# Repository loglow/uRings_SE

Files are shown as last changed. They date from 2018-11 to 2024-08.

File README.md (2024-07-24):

# µRings SE (uRings, microRings) Eurorack [Rev D]

## 8HP Eurorack module | Resonator

[μRings SE](http://urings-se.com) is a resonator, transforming unpitched external excitation signals into pitched sounds by modeling the vibrations of bars, tubes, and strings.

This re-engineered Eurorack module updates and simplifies the classic [Mutable Instruments Rings](https://mutable-instruments.net/modules/rings/) design by miniaturizing the module from 14HP to 8HP and redesigning the front panel layout without eliminating any original functionality.

Fully compatible with upstream Rings firmware. Includes power cable, mounting hardware, and a one-year warranty. Designed and built with care by [Tall Dog Electronics](http://tall-dog.com) in Western Massachusetts. Licensed [CC BY-SA 4.0](https://creativecommons.org/licenses/by-sa/4.0/) open source hardware.

- **Height:** 3U (128.5 mm)
- **Width:** 8HP (40.3 mm)
- **Depth:** 43 mm (with power)
- **+12V:** 120 mA (average)
- **-12V:** 5 mA (average)

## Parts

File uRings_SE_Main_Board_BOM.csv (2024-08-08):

Ref | Qty | Desc | Mfg | MPN
C1 C2 C5 C12 C13 C15 C16 C18 C19 C21 C22 C26 C33 C34 C35 C36 C44 C47 | 18 | CAP CER 0.1UF 16V X7R 0603 | Samsung Electro-Mechanics | CL10B104KO8NNWC
C3 C9 | 2 | CAP CER 2.2UF 10V X7R 0603 | TDK Corporation | C1608X7R1A225M080AC
C4 C7 C20 C25 C32 C40 | 6 | CAP CER 18PF 50V C0G/NPO 0603 | YAGEO | CC0603FPNPO9BN180
C6 C11 C17 C23 | 4 | CAP CER 1UF 25V X7R 0603 | Taiyo Yuden | TMK107B7105KA-T
C8 C10 C14 C24 C27 C28 C41 C42 | 8 | CAP ALUM 10UF 20% 25V SMD | Würth Elektronik | 865230440002
C29 C30 C31 C38 | 4 | CAP CER 10000PF 50V C0G 0603 | TDK Corporation | C1608C0G1H103J080AA
C37 C39 | 2 | CAP CER 2200PF 50V C0G 0603 | TDK Corporation | C1608C0G1H222J080AA
C43 | 1 | CAP CER 220PF 50V C0G/NPO 0603 | YAGEO | CC0603FPNPO9BN221
C45 C46 C49 | 3 | CAP ALUM 47UF 20% 25V SMD | Würth Elektronik | 865230445005
C48 | 1 | CAP ALUM 22UF 20% 25V SMD | Würth Elektronik | 865230443003
D1 | 1 | DIODE ARR SCHOTT 30V 200MA SOT23 | Toshiba Semiconductor and Storage | TBAT54S,LM
D2 D3 | 2 | DIODE SCHOTTKY 40V 1A SOD123 | Diodes Incorporated | 1N5819HW-7-F
H1 H2 H3 H4 | 4 | CONN HDR 10POS 0.1 GOLD PCB | Sullins Connector Solutions | PPPC052LFBN-RC
H5 | 1 | CONN HEADER VERT 10POS 1.27MM | CNC Tech | 3220-10-0100-00
H6 | 1 | DO NOT POPULATE | DNP | DNP
H7 | 1 | CONN HEADER VERT 10POS 2.54MM | On Shore Technology Inc. | 302-S101
L1 L2 L3 | 3 | FERRITE BEAD 1K OHM 0603 1LN | Würth Elektronik | 742792664
Q1 | 1 | TRANS NPN 40V 0.2A SOT23-3 | Diodes Incorporated | MMBT3904-7-F
R1 R11 | 2 | RES SMD 10K OHM 1% 1/10W 0603 | Panasonic Electronic Components | ERJ-3EKF1002V
R2 R3 | 2 | RES SMD 100 OHM 1% 1/10W 0603 | Panasonic Electronic Components | ERJ-3EKF1000V
R4 | 1 | RES 3.3M OHM 0.1% 1/4W 1206 | Susumu | RG3216P-3304-B-T1
R5 R6 R48 | 3 | RES SMD 2.2K OHM 1% 1/10W 0603 | Panasonic Electronic Components | ERJ-3EKF2201V
R7 R45 | 2 | RES SMD 36K OHM 0.1% 1/10W 0603 | Susumu | RG1608P-363-B-T5
R8 R9 R10 R18 R26 R38 R39 R40 | 8 | RES SMD 100K OHM 0.1% 1/10W 0603 | Susumu | RG1608P-104-B-T5
R12 R13 R14 R35 R36 | 5 | RES SMD 120K OHM 0.1% 1/10W 0603 | Susumu | RG1608P-124-B-T5
R15 R16 R17 R32 R33 | 5 | RES SMD 20K OHM 0.1% 1/10W 0603 | Susumu | RG1608P-203-B-T5
R19 R21 R23 R25 R29 R31 R34 | 7 | RES SMD 47K OHM 0.1% 1/10W 0603 | Susumu | RG1608P-473-B-T5
R20 R30 R46 | 3 | RES SMD 6.8K OHM 0.1% 1/10W 0603 | Susumu | RG1608P-682-B-T5
R22 R24 | 2 | RES SMD 1K OHM 0.1% 1/10W 0603 | Susumu | RG1608P-102-B-T5
R27 | 1 | RES SMD 1M OHM 0.1% 1/4W 1206 | Susumu | RG3216P-1004-B-T1
R28 | 1 | RES SMD 470K OHM 0.1% 1/4W 1206 | Susumu | RG3216P-4703-B-T1
R37 | 1 | RES SMD 180K OHM 0.1% 1/10W 0603 | Susumu | RG1608P-184-B-T5
R41 R42 R43 R44 | 4 | RES SMD 180 OHM 1% 1/10W 0603 | Panasonic Electronic Components | ERJ-3EKF1800V
R47 | 1 | RES SMD 4.7 OHM 5% 1/4W 1206 | Panasonic Electronic Components | ERJ-8GEYJ4R7V
U1 | 1 | IC MCU 32BIT 1MB FLASH 64LQFP | STMicroelectronics | STM32F405RGT6
U2 | 1 | IC MUX 8:1 120OHM 16TSSOP | Nexperia USA Inc. | 74HC4051PW,118
U3 | 1 | IC CODEC AUDIO LOW POWER 28LFCSP | Analog Devices Inc. | SSM2603CPZ-REEL7
U4 | 1 | IC OPAMP GP 4 CIRCUIT 14TSSOP | Microchip Technology | MCP6004T-E/ST
U5 | 1 | IC OPAMP GP 2 CIRCUIT 8MSOP | Microchip Technology | MCP6002T-I/MS
U6 | 1 | IC OPAMP JFET 2 CIRCUIT 8TSSOP | Texas Instruments | TL072CPWR
U7 | 1 | IC REG LINEAR 3.3V 800MA SOT223 | Texas Instruments | LM1117IMP-3.3/NOPB
U8 | 1 | IC VREF SHUNT 0.5% SOT23-3 | Texas Instruments | LM4040C10IDBZR
X1 | 1 | CRYSTAL 8.0000MHZ 18PF SMD | Abracon LLC | ABM3-8.000MHZ-D2Y-T
X2 | 1 | CRYSTAL 12.2880MHZ 18PF SMD | Abracon LLC | ABM3-12.288MHZ-D2Y-T

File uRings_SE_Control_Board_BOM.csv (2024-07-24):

Ref | Qty | Desc | Mfg | MPN
D1 D2 | 2 | LED GRN/RED DIFF 3MM ROUND T/H | Kingbright | WP3VEGW
H1 H2 H3 H4 | 4 | CONN HEADER 10POS .100 STR 15AU | Amphenol ICC (FCI) | 67997-210HLF
J1 J2 J3 J4 J5 J6 J7 J8 J9 J10 | 10 | 3.5MM JACK VERTICAL PCB MOUNT | Wenzhou QingPu | WQP-WQP518MA
P1 P3 P5 P7 P9 | 5 | POT 9MM LINEAR B10K WHITE LINE | Song Huei | R0904N-B10K,L-25KQ/LWS
P2 P4 P6 P8 P10 | 5 | POT 9MM LINEAR B10K WHITE LINE CENTER DETENT | Song Huei | R0904N-B10K,L-25KQ/LWS/CC
S1 S2 | 2 | SWITCH TACTILE SPST-NO 0.05A 12V | E-Switch | TL1105DF160Q

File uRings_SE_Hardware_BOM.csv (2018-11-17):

Description | Quantity
Thonkiconn Knurled Nut, Steel, M6 | 10
Threaded Hex Standoff, Brass, M2.5 x 11 mm | 2
Standoff Screw, Button Head, Hex Socket, M2.5 x 6 mm | 4

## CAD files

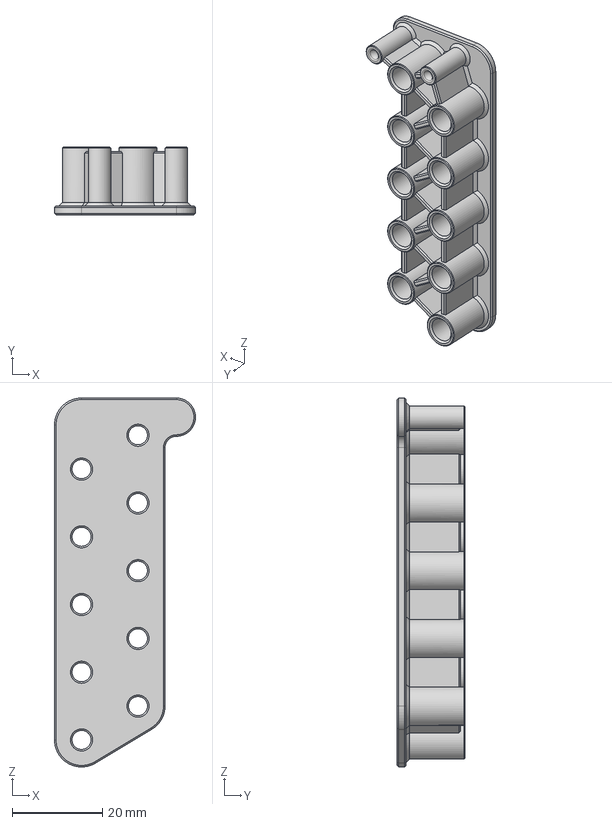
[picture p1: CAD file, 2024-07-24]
uRings_SE_Assembly_Cap.step
31.2 x 15.0 x 81.7 mm

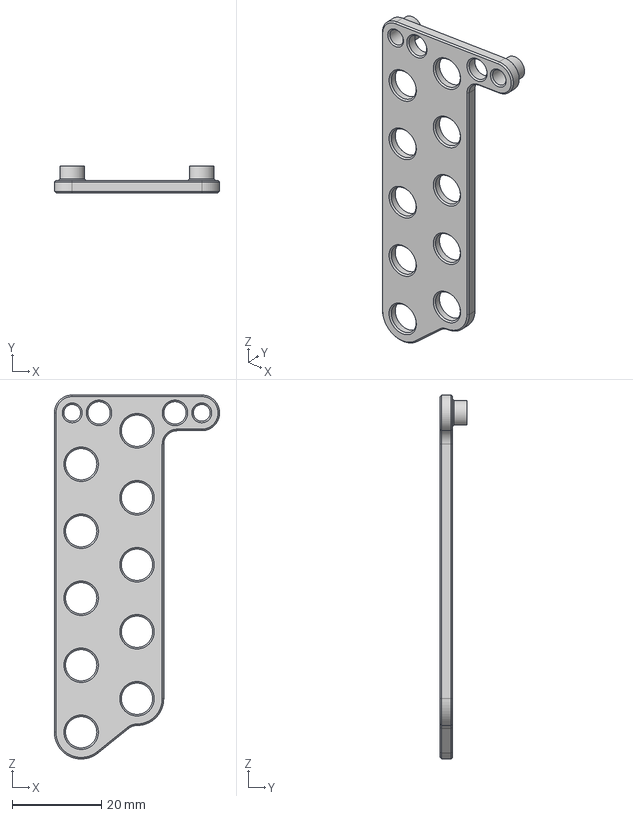
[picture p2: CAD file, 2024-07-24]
uRings_SE_Assembly_Spacer.step
37.0 x 6.00 x 81.5 mm

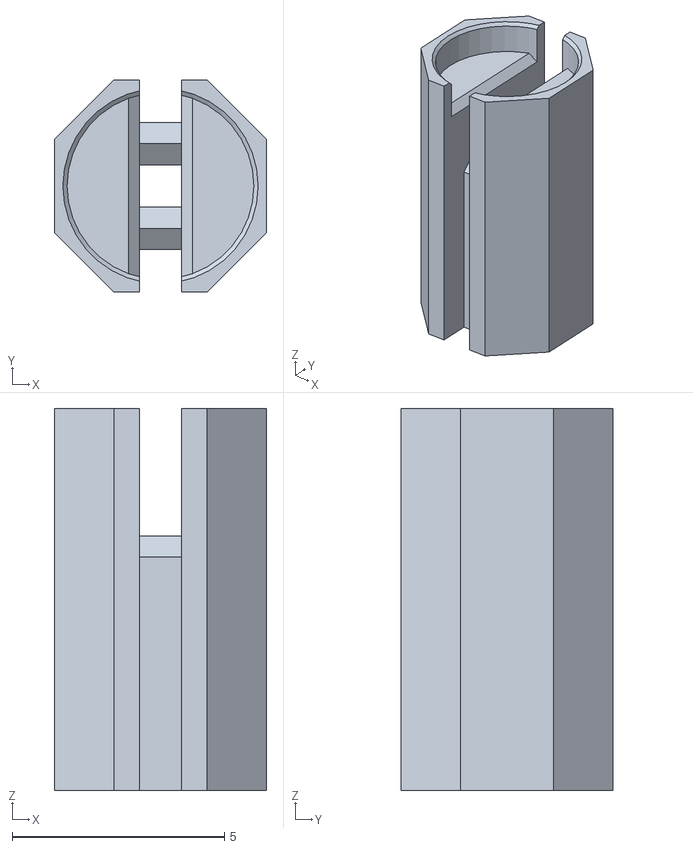
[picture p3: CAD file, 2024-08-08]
uRings_SE_LED_Spacer.stl
5.00 x 5.00 x 9.00

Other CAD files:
uRings_SE_Assembly_Cap.stl
uRings_SE_Assembly_Spacer.stl
uRings_SE_Model.skp

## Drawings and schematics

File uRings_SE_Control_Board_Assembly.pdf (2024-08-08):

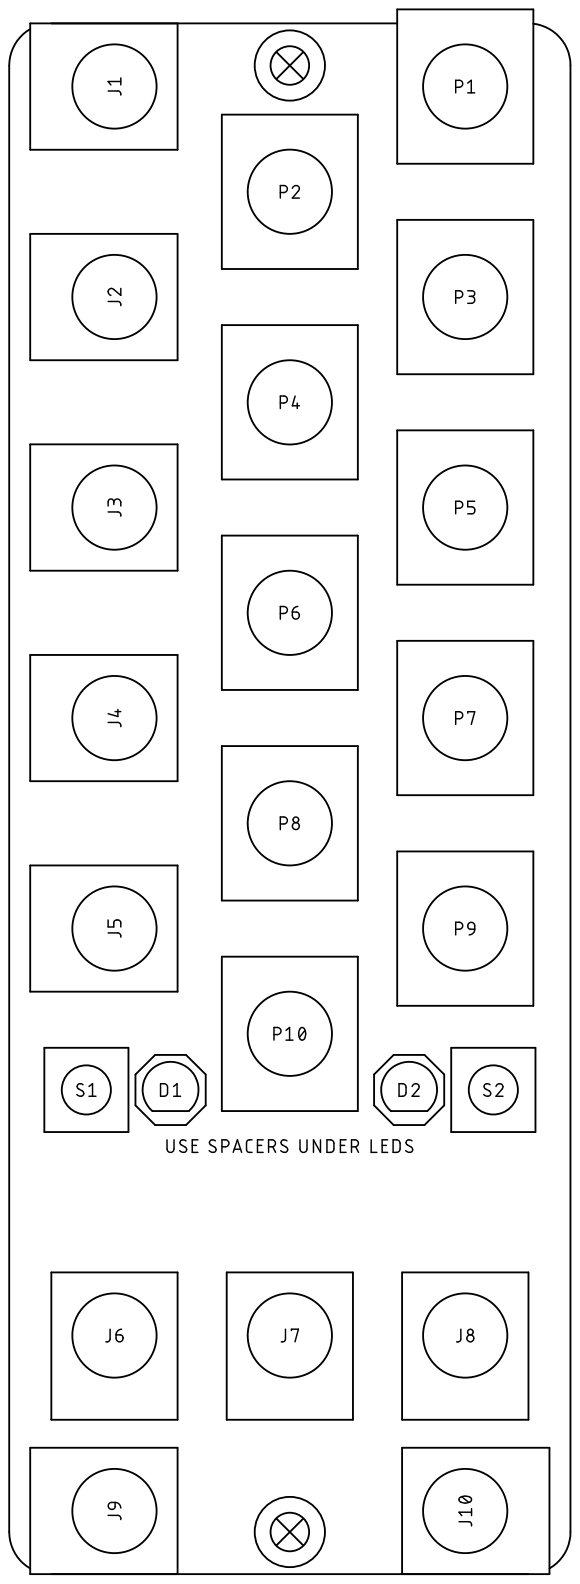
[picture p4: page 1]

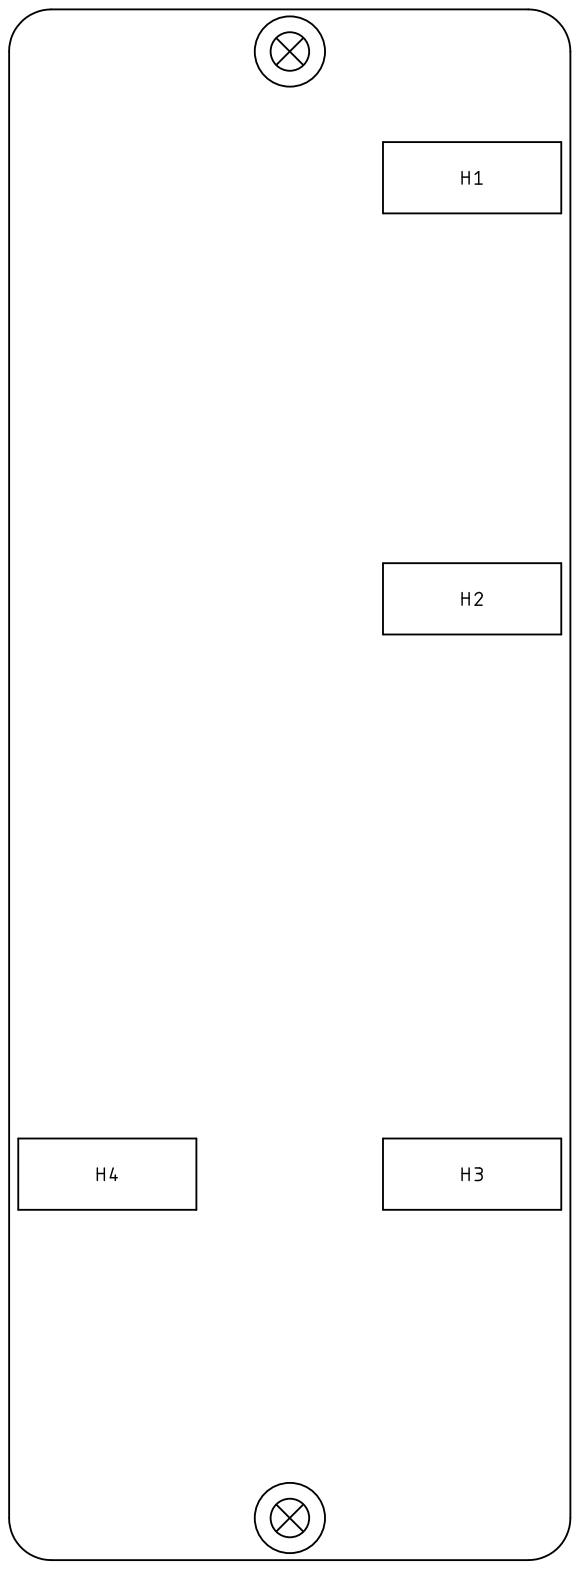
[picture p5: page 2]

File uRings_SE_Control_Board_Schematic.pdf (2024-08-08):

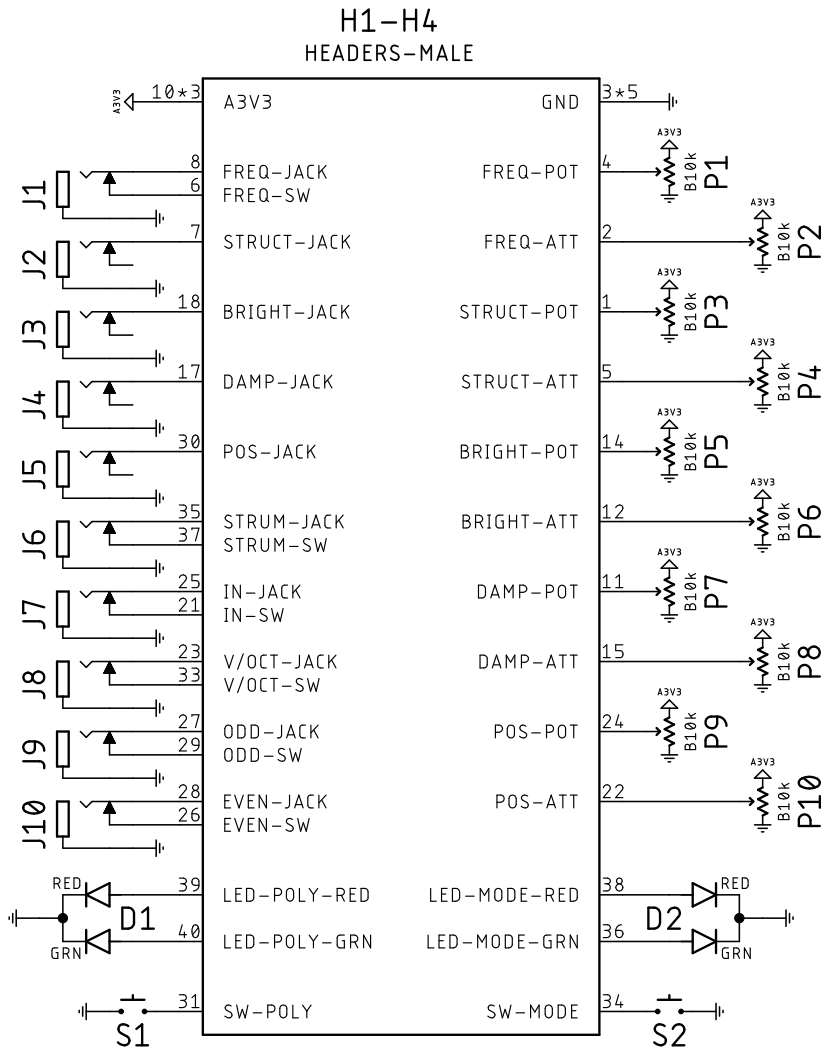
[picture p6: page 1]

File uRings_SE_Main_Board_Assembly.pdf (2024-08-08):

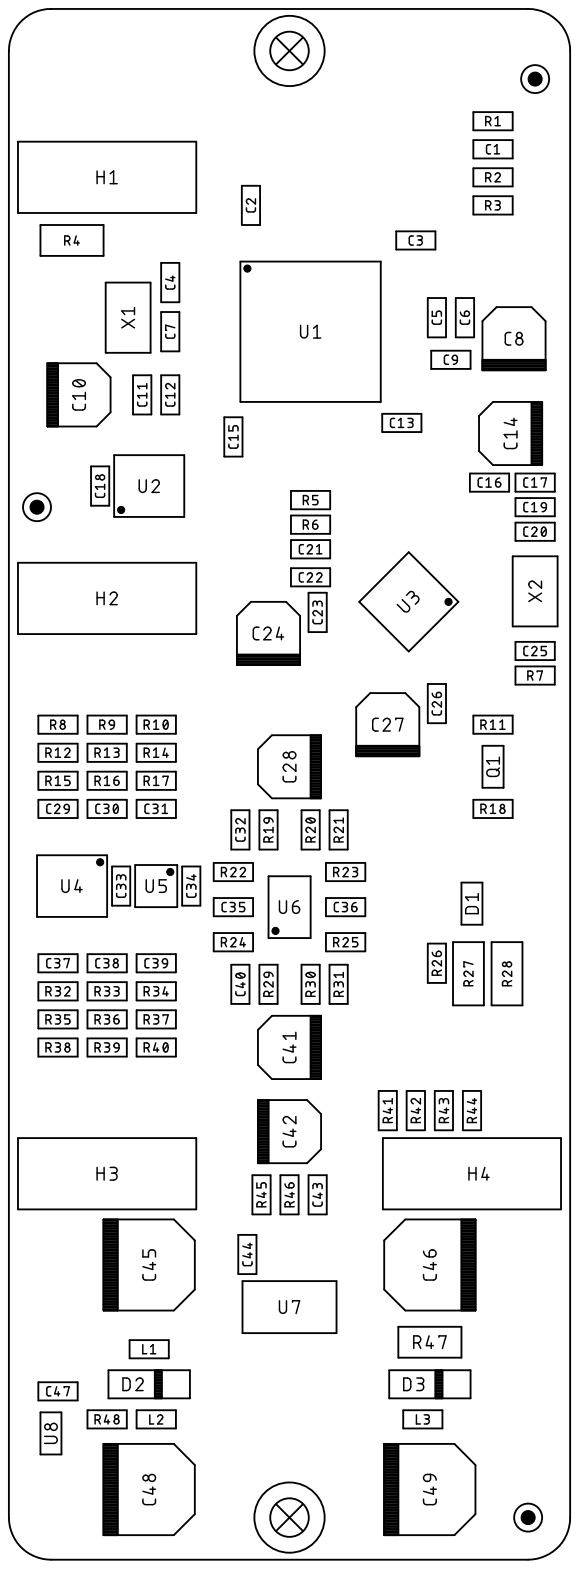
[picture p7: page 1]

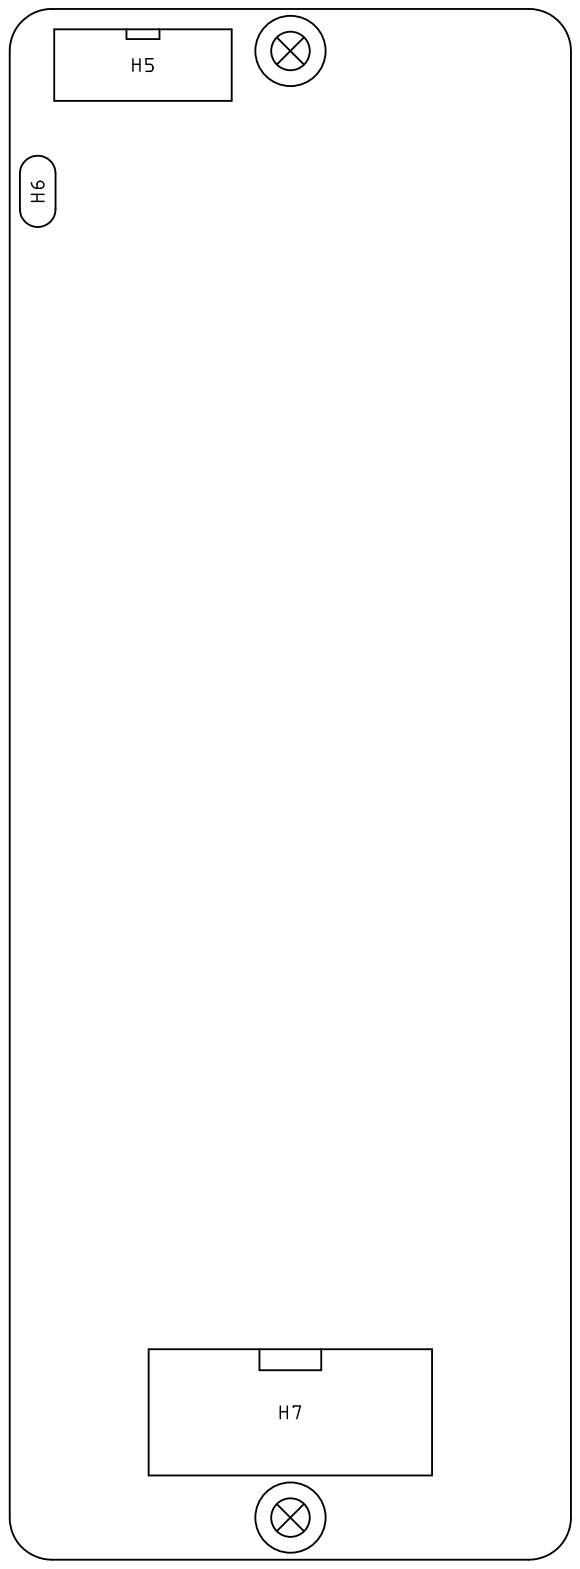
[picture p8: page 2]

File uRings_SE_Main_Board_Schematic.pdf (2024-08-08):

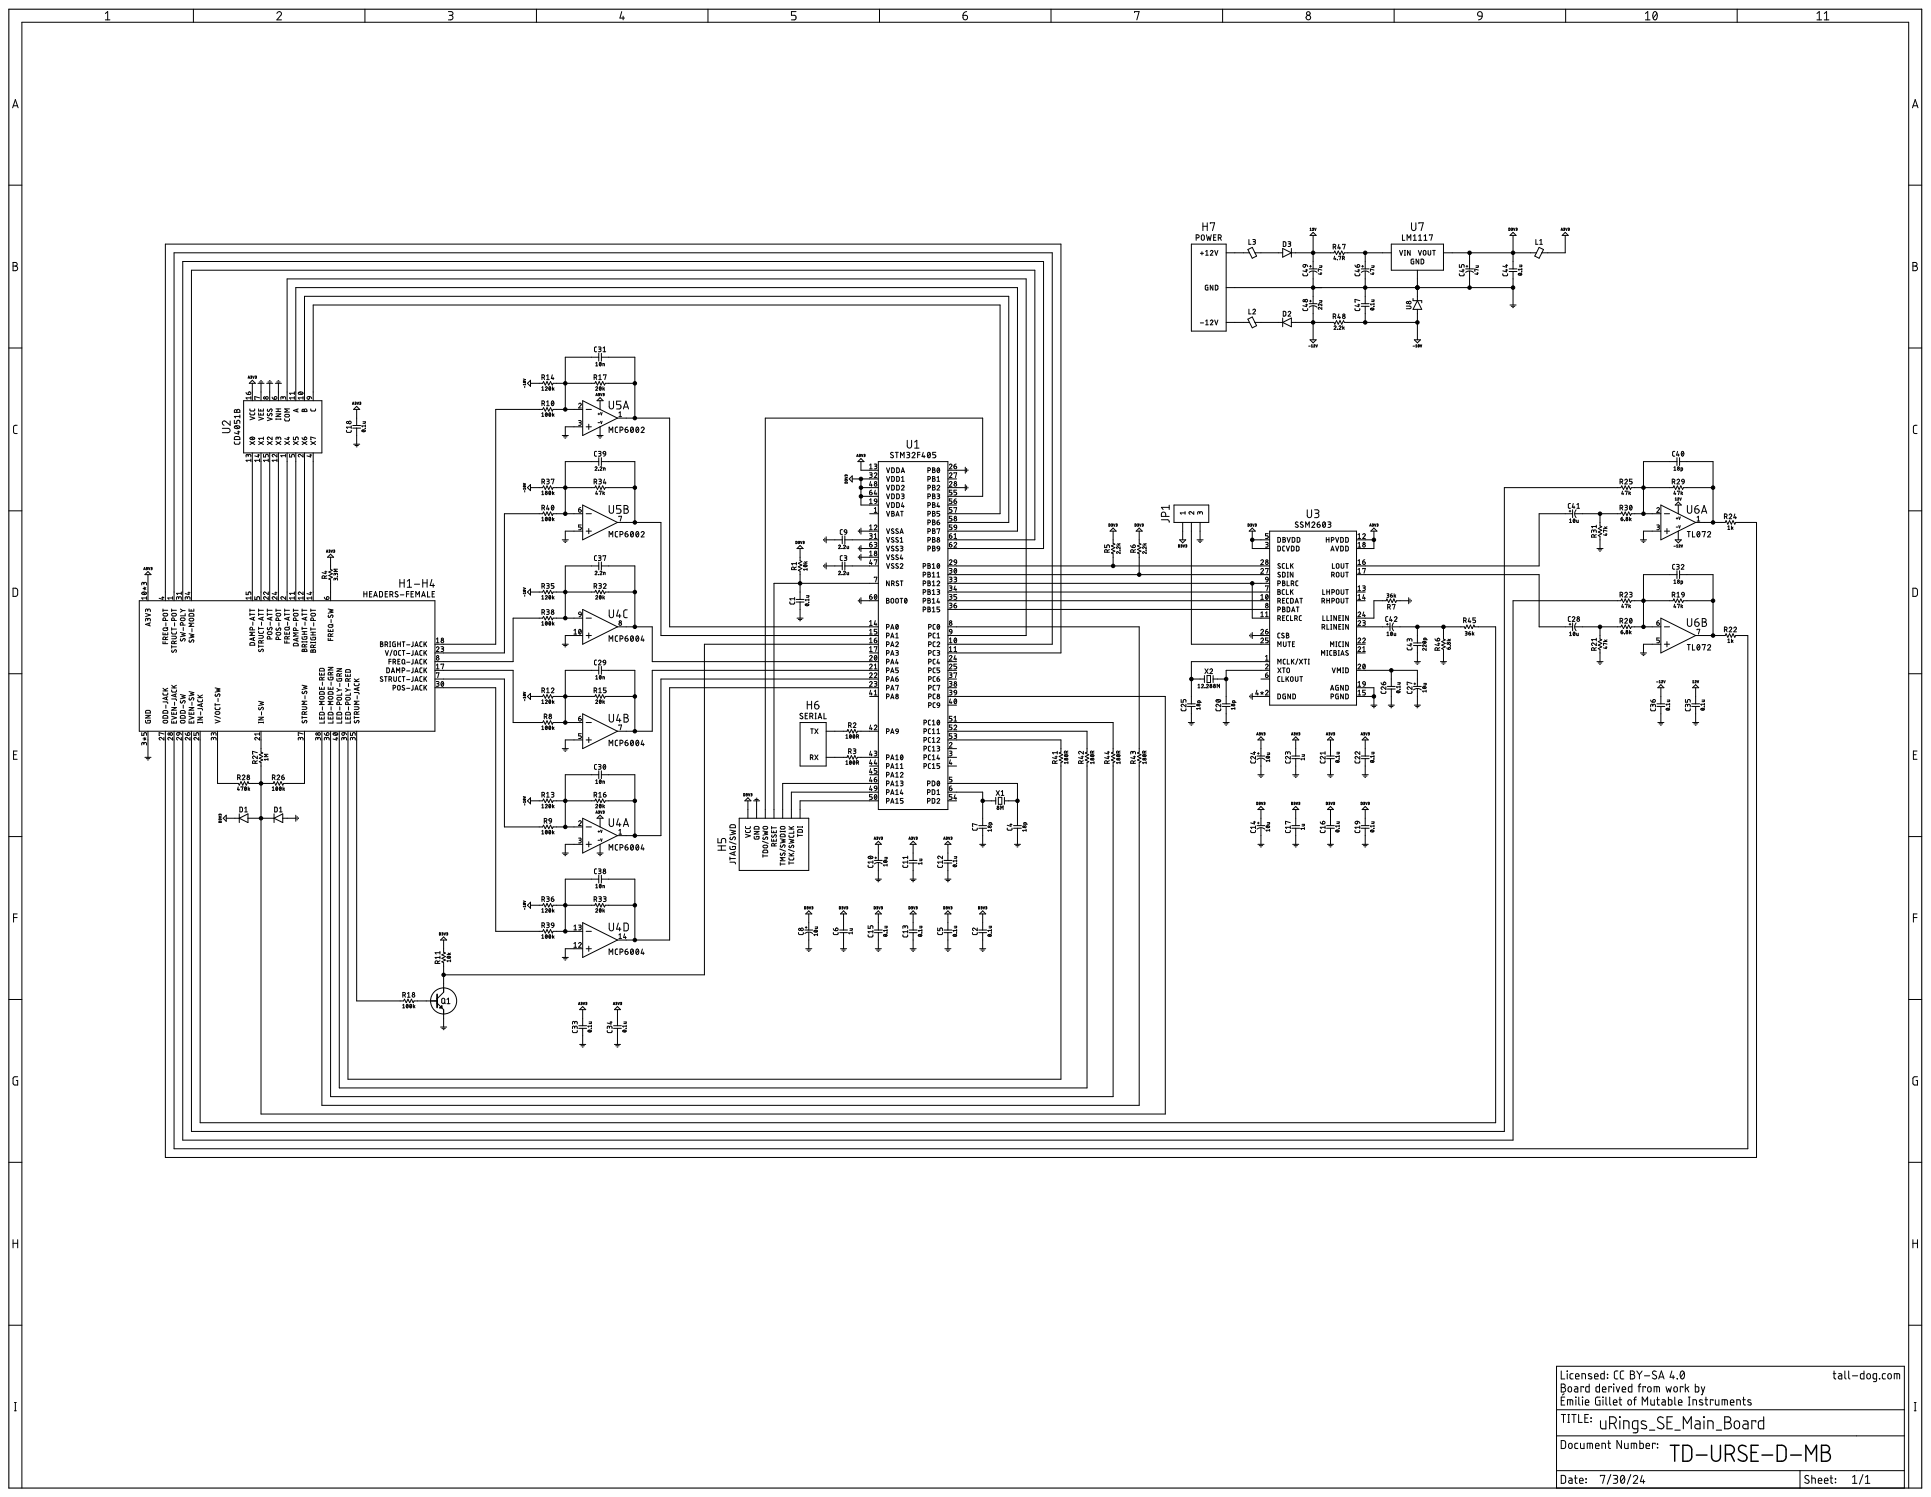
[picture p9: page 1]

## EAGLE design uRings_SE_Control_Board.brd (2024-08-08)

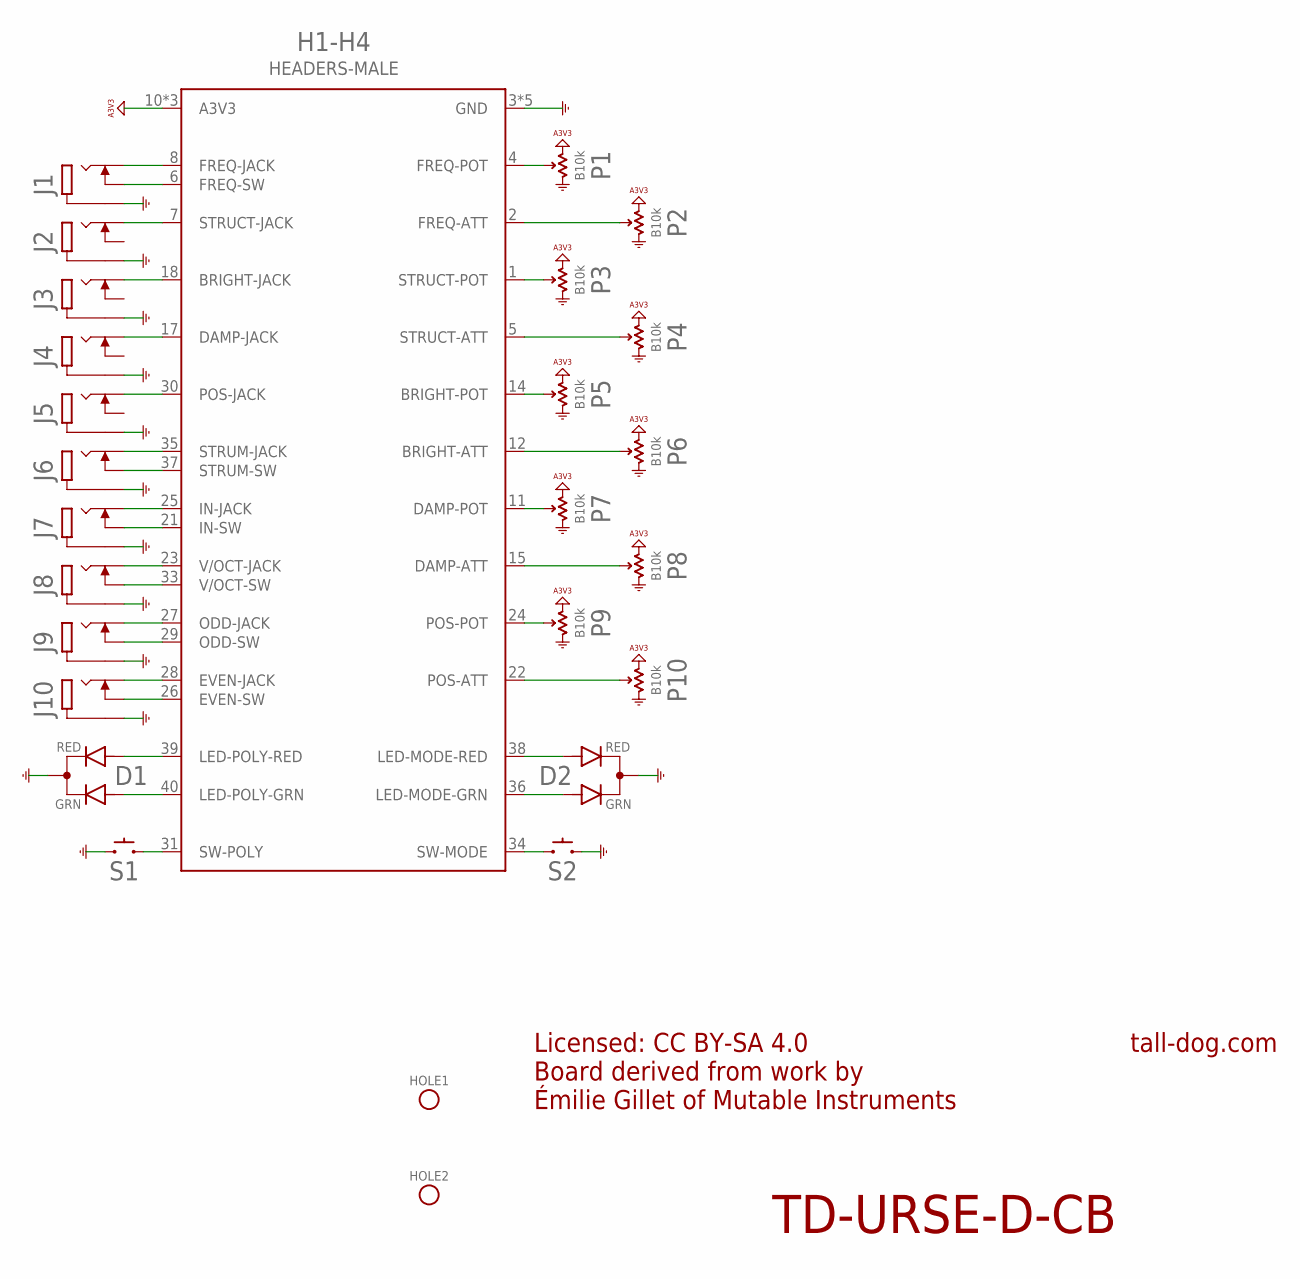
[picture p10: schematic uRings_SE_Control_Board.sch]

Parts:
D1, D2: LED-DUAL; LED-T1-3
H1-H4: HEADERS-MALE
HOLE1, HOLE2: HOLE; M2.5-HOLE
J1, J2, J3, J4, J5, J6, J7, J8, J9, J10: JACK
P1, P2, P3, P4, P5, P6, P7, P8, P9, P10: B10k; POT
S1, S2: SPST; TL1105

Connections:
A3V3: H1-H4.10 (A3V3), H1-H4.16 (A3V3), H1-H4.20 (A3V3), P1.P$1 (E), P2.P$1 (E), P3.P$1 (E), P4.P$1 (E), P5.P$1 (E), P6.P$1 (E), P7.P$1 (E), P8.P$1 (E), P9.P$1 (E), P10.P$1 (E)
BRIGHT-ATT: H1-H4.12 (BRIGHT-ATT), P6.P$2 (S)
BRIGHT-JACK: H1-H4.18 (BRIGHT-JACK), J3.P3 (3)
BRIGHT-POT: H1-H4.14 (BRIGHT-POT), P5.P$2 (S)
DAMP-ATT: H1-H4.15 (DAMP-ATT), P8.P$2 (S)
DAMP-JACK: H1-H4.17 (DAMP-JACK), J4.P3 (3)
DAMP-POT: H1-H4.11 (DAMP-POT), P7.P$2 (S)
EVEN-JACK: H1-H4.28 (EVEN-JACK), J10.P3 (3)
EVEN-SW: H1-H4.26 (EVEN-SW), J10.P2 (2)
FREQ-ATT: H1-H4.2 (FREQ-ATT), P2.P$2 (S)
FREQ-JACK: H1-H4.8 (FREQ-JACK), J1.P3 (3)
FREQ-POT: H1-H4.4 (FREQ-POT), P1.P$2 (S)
FREQ-SW: H1-H4.6 (FREQ-SW), J1.P2 (2)
GND: D1.2 (C), D2.2 (C), H1-H4.3 (GND), H1-H4.9 (GND), H1-H4.13 (GND), H1-H4.19 (GND), H1-H4.32 (GND), J1.P1 (1), J2.P1 (1), J3.P1 (1), J4.P1 (1), J5.P1 (1), J6.P1 (1), J7.P1 (1), J8.P1 (1), J9.P1 (1), J10.P1 (1), P1.P$3 (A), P2.P$3 (A), P3.P$3 (A), P4.P$3 (A), P5.P$3 (A), P6.P$3 (A), P7.P$3 (A), P8.P$3 (A), P9.P$3 (A), P10.P$3 (A), S1.1, S1.2 (1), S2.1, S2.2 (1)
IN-JACK: H1-H4.25 (IN-JACK), J7.P3 (3)
IN-SW: H1-H4.21 (IN-SW), J7.P2 (2)
LED-MODE-GRN: D2.3 (GRN), H1-H4.36 (LED-MODE-GRN)
LED-MODE-RED: D2.1 (RED), H1-H4.38 (LED-MODE-RED)
LED-POLY-GRN: D1.3 (GRN), H1-H4.40 (LED-POLY-GRN)
LED-POLY-RED: D1.1 (RED), H1-H4.39 (LED-POLY-RED)
ODD-JACK: H1-H4.27 (ODD-JACK), J9.P3 (3)
ODD-SW: H1-H4.29 (ODD-SW), J9.P2 (2)
POS-ATT: H1-H4.22 (POS-ATT), P10.P$2 (S)
POS-JACK: H1-H4.30 (POS-JACK), J5.P3 (3)
POS-POT: H1-H4.24 (POS-POT), P9.P$2 (S)
STRUCT-ATT: H1-H4.5 (STRUCT-ATT), P4.P$2 (S)
STRUCT-JACK: H1-H4.7 (STRUCT-JACK), J2.P3 (3)
STRUCT-POT: H1-H4.1 (STRUCT-POT), P3.P$2 (S)
STRUM-JACK: H1-H4.35 (STRUM-JACK), J6.P3 (3)
STRUM-SW: H1-H4.37 (STRUM-SW), J6.P2 (2)
SW-MODE: H1-H4.34 (SW-MODE), S2.3 (2), S2.4 (2)
SW-POLY: H1-H4.31 (SW-POLY), S1.3 (2), S1.4 (2)
V/OCT-JACK: H1-H4.23 (V/OCT-JACK), J8.P3 (3)
V/OCT-SW: H1-H4.33 (V/OCT-SW), J8.P2 (2)

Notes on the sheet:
Licensed: CC BY-SA 4.0 Board derived from work by Émilie Gillet of Mutable Instruments
tall-dog.com
TD-URSE-D-CB

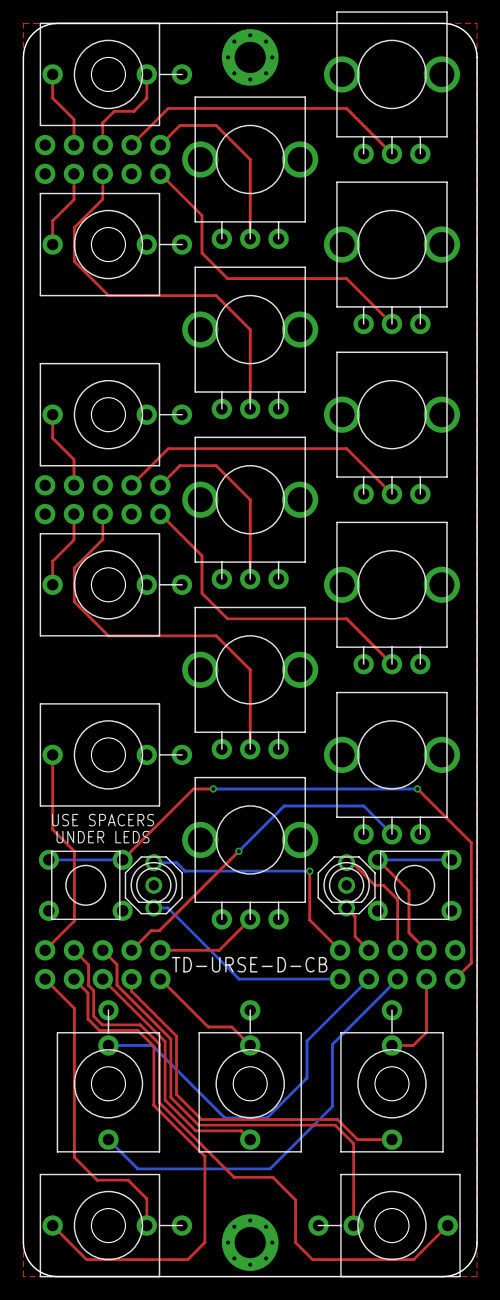
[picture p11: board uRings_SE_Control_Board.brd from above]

Board: 2 copper layers, 40.0 x 110.5 mm, 29 parts (0 on the bottom side), 34 nets.

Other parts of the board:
U$1, U$2: LED-SPACER

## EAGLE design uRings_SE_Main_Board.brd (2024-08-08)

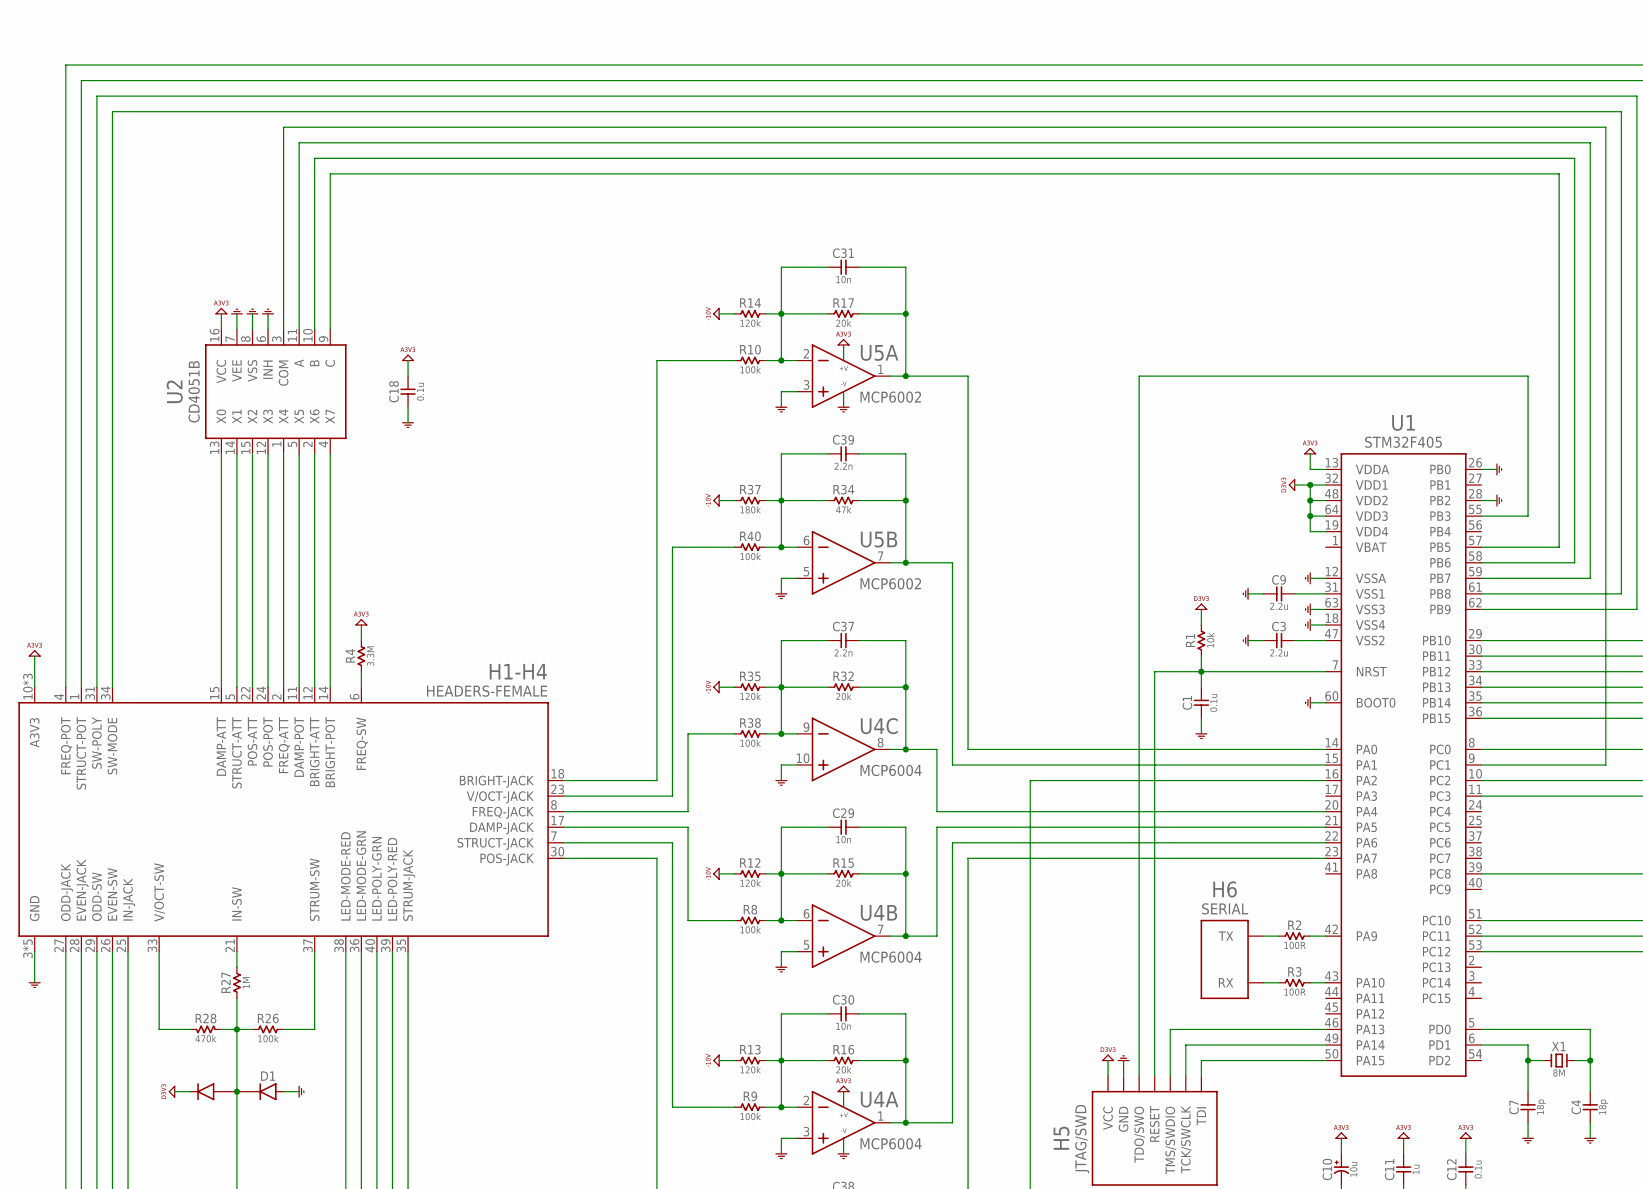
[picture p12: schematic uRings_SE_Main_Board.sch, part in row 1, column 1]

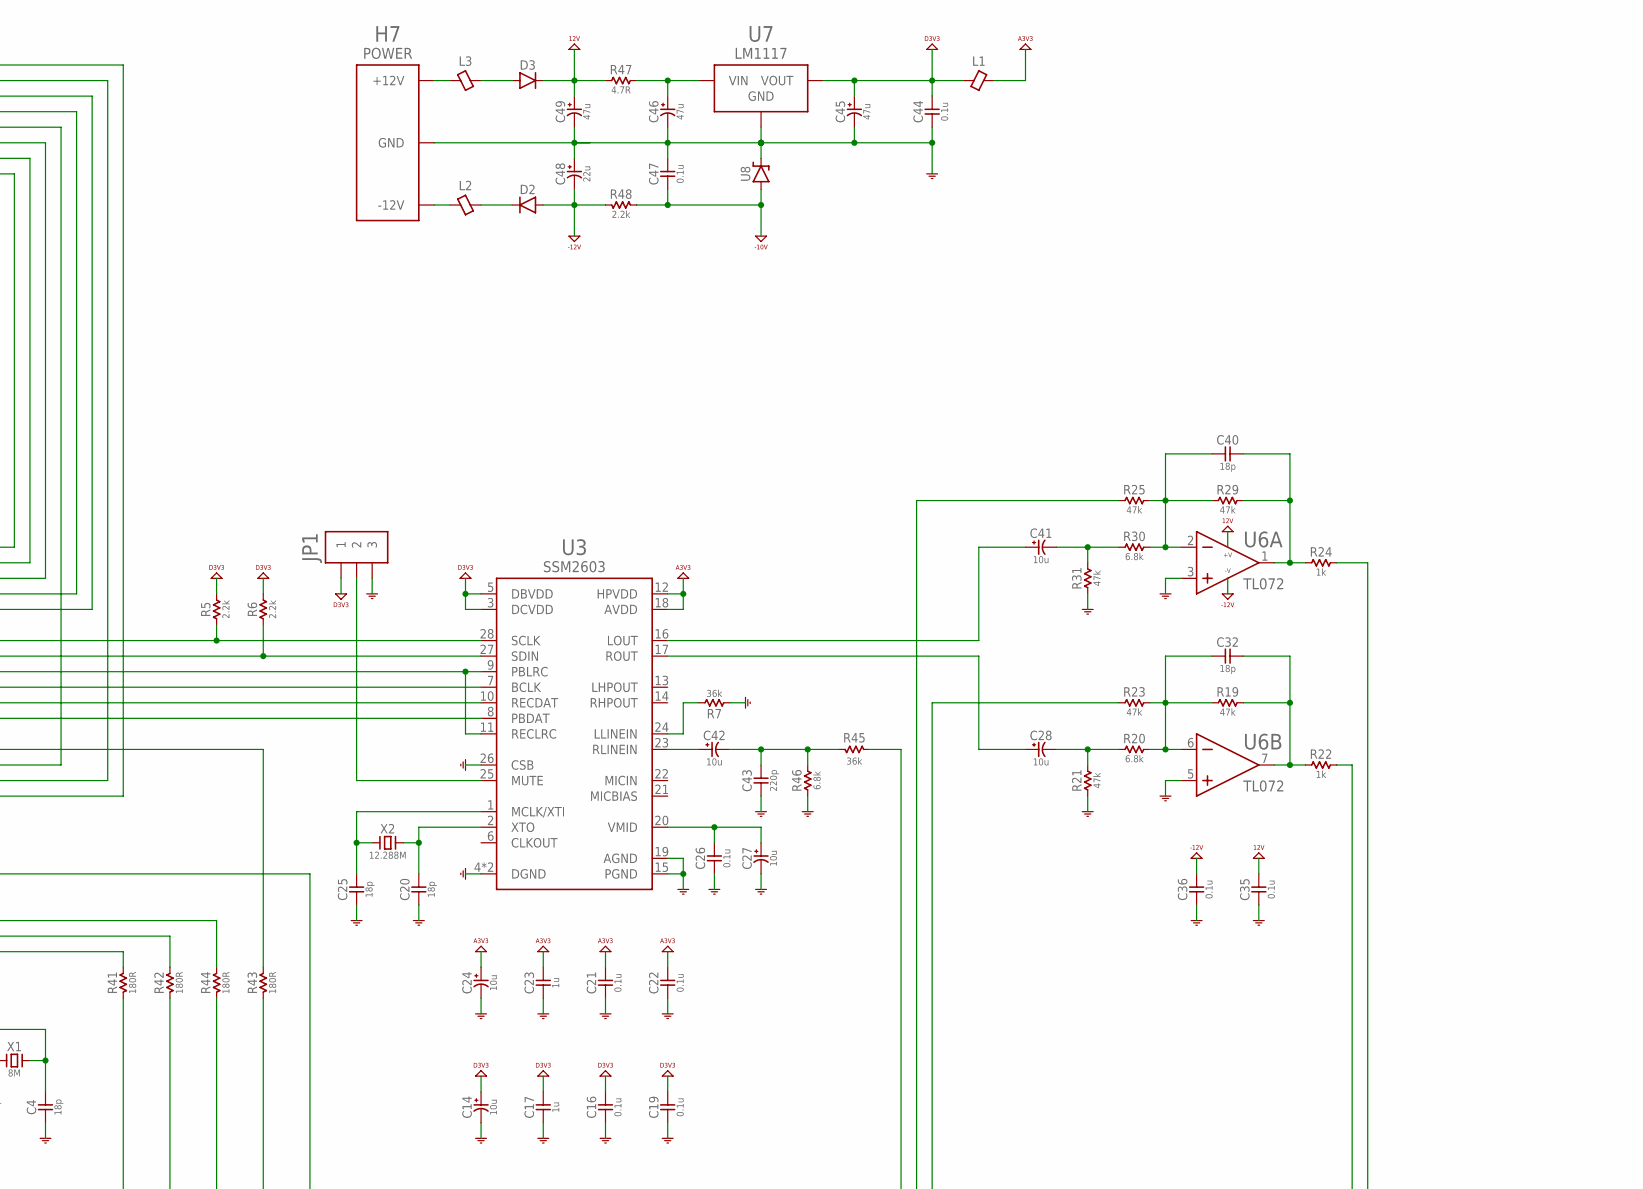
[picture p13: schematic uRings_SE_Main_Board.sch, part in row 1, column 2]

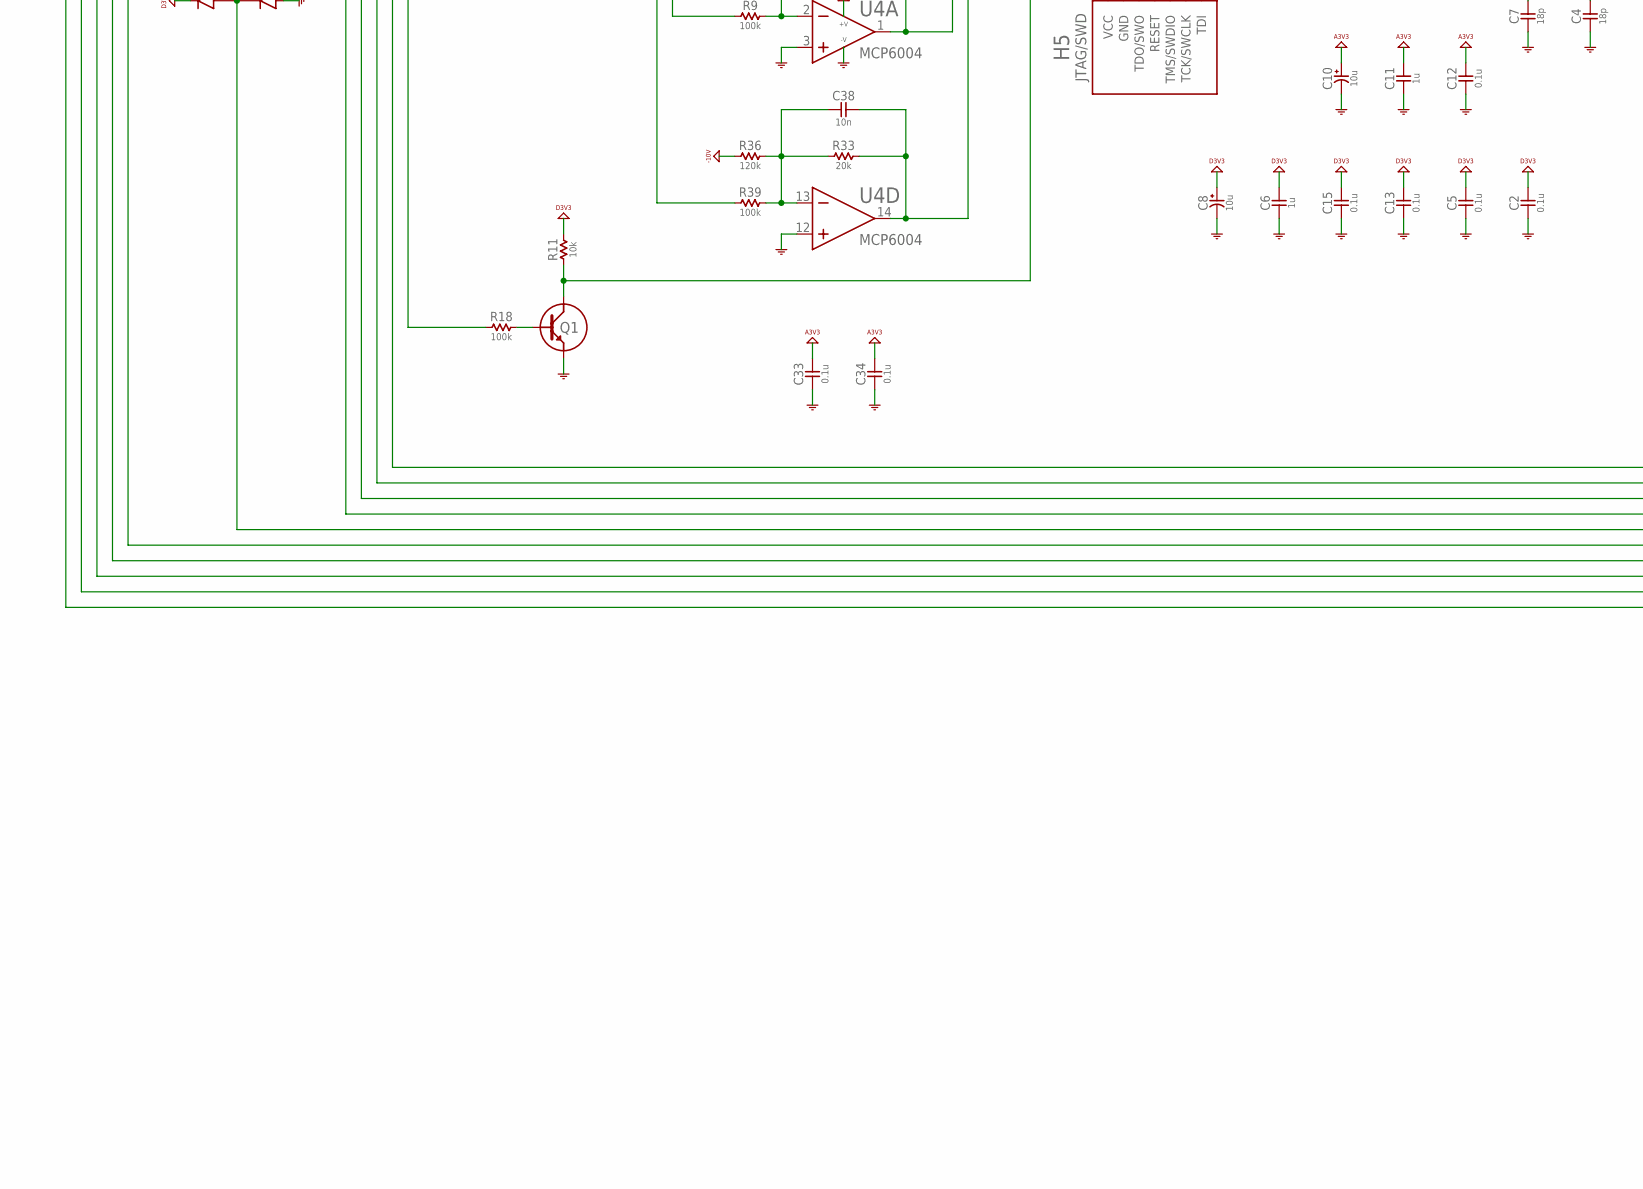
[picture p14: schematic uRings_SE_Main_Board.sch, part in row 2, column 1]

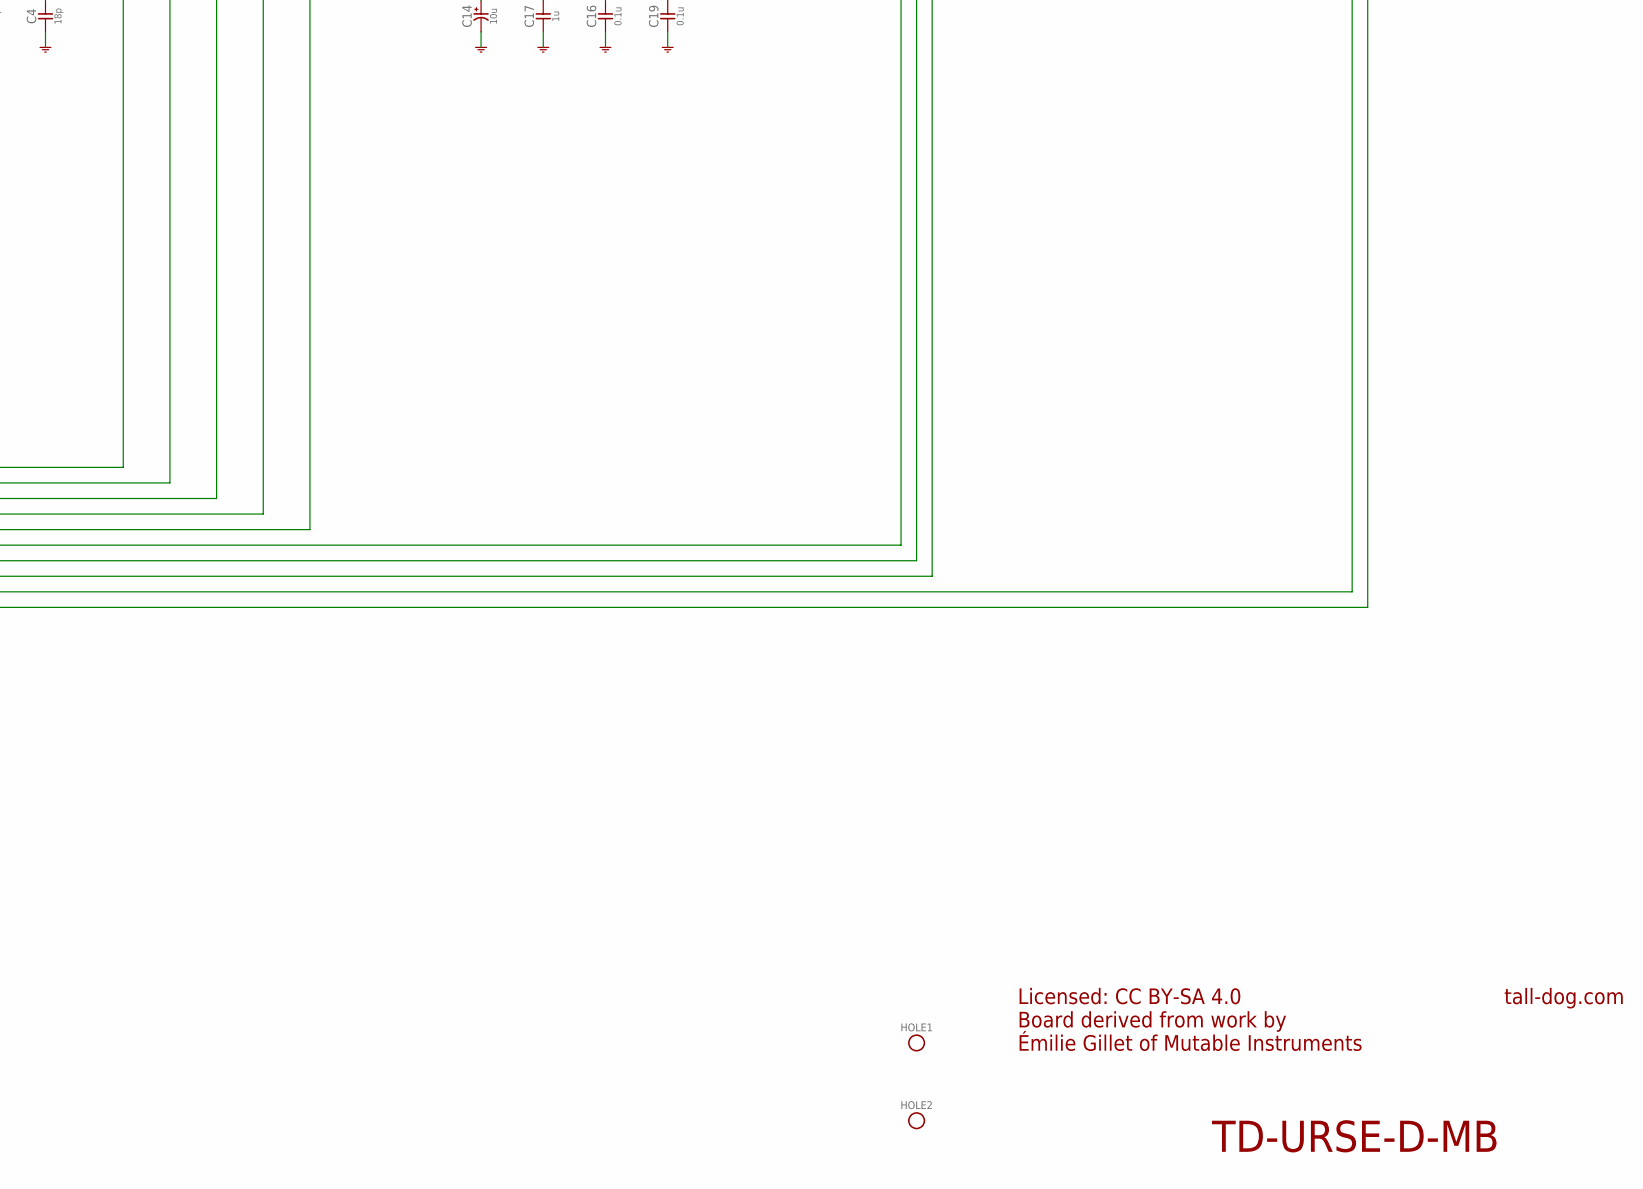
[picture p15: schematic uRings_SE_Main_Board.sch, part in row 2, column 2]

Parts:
C1, C2, C5, C12, C13, C15, C16, C18, C19, C21, C22, C26, C33, C34, C35, C36, C44, C47: 0.1u; 0603-NP
C3, C9: 2.2u; 0603-NP
C4, C7, C20, C25, C32, C40: 18p; 0603-NP
C6, C11, C17, C23: 1u; 0603-NP
C8, C10, C14, C24, C27, C28, C41, C42: 10u; ELECTRO-SMD-4.3MM
C29, C30, C31, C38: 10n; 0603-NP
C37, C39: 2.2n; 0603-NP
C43: 220p; 0603-NP
C45, C46, C49: 47u; ELECTRO-SMD-6.6MM
C48: 22u; ELECTRO-SMD-6.6MM
D1: DIODE-DUAL; SOT-23
D2, D3: DIODE; SOD-123
H1-H4: HEADERS-FEMALE
H5: JTAG/SWD; PTH-0.05-2X5-SHROUDED
H6: SERIAL
H7: POWER; PTH-0.1-2X5-SHROUDED
HOLE1, HOLE2: HOLE; M2.5-HOLE
JP1: JUMPER-3
L1, L2, L3: FERRITE-BEAD-0603; 0603-NP
Q1: NPN; SOT-23
R1, R11: 10k; 0603-NP
R2, R3: 100R; 0603-NP
R4: 3.3M; 1206-NP
R5, R6, R48: 2.2k; 0603-NP
R7, R45: 36k; 0603-NP
R8, R9, R10, R18, R26, R38, R39, R40: 100k; 0603-NP
R12, R13, R14, R35, R36: 120k; 0603-NP
R15, R16, R17, R32, R33: 20k; 0603-NP
R19, R21, R23, R25, R29, R31, R34: 47k; 0603-NP
R20, R30, R46: 6.8k; 0603-NP
R22, R24: 1k; 0603-NP
R27: 1M; 1206-NP
R28: 470k; 1206-NP
R37: 180k; 0603-NP
R41, R42, R43, R44: 180R; 0603-NP
R47: 4.7R; 1206-NP
U1: STM32F405; LQFP-64
U2: CD4051B; TSSOP-16
U3: SSM2603; QFN-28
U4: MCP6004; TSSOP-14
U5: MCP6002; MSOP-8
U6: TL072; TSSOP-8
U7: LM1117; SOT-223
U8: ZENER; SOT-23
X1: 8M; CRYSTAL-ABM3
X2: 12.288M; CRYSTAL-ABM3

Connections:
12V: C35.2, C49.A (POS), D3.C, R47.1, U6.8 (POS)
-10V: C47.2, R12.1, R13.1, R14.1, R35.1, R36.1, R37.1, R48.1, U8.2 (A)
-12V: C36.1, C48.C (NEG), D2.A, R48.2, U6.4 (NEG)
A3V3: C10.A (POS), C11.2, C12.2, C18.2, C21.2, C22.2, C23.2, C24.A (POS), C33.2, C34.2, H1-H4.10 (A3V3), H1-H4.16 (A3V3), H1-H4.20 (A3V3), L1.2, R4.2, U1.13 (VDDA), U2.16 (VCC), U3.12 (HPVDD), U3.18 (AVDD), U4.4 (POS), U5.8 (POS)
BRIGHT-ATT: H1-H4.12 (BRIGHT-ATT), U2.2 (X6)
BRIGHT-CV: C31.2, R17.2, U1.14 (PA0), U5.1 (OUT)
BRIGHT-JACK: H1-H4.18 (BRIGHT-JACK), R10.1
BRIGHT-POT: H1-H4.14 (BRIGHT-POT), U2.4 (X7)
D3V3: C2.2, C5.2, C6.2, C8.A (POS), C13.2, C14.A (POS), C15.2, C16.2, C17.2, C19.2, C44.2, C45.A (POS), D1.2 (C2), H5.1 (VCC), JP1.1, L1.1, R1.2, R5.2, R6.2, R11.2, U1.19 (VDD4), U1.32 (VDD1), U1.48 (VDD2), U1.64 (VDD3), U3.3 (DCVDD), U3.5 (DBVDD), U7.2 (VOUT), U7.4 (VOUT)
DAMP-ATT: H1-H4.15 (DAMP-ATT), U2.13 (X0)
DAMP-CV: C29.2, R15.2, U1.21 (PA5), U4.7 (OUT)
DAMP-JACK: H1-H4.17 (DAMP-JACK), R8.1
DAMP-POT: H1-H4.11 (DAMP-POT), U2.5 (X5)
EVEN-JACK: H1-H4.28 (EVEN-JACK), R22.2
EVEN-OUT: C28.A (POS), U3.17 (ROUT)
EVEN-SW: H1-H4.26 (EVEN-SW), R25.1
FREQ-ATT: H1-H4.2 (FREQ-ATT), U2.1 (X4)
FREQ-CV: C37.2, R32.2, U1.20 (PA4), U4.8 (OUT)
FREQ-JACK: H1-H4.8 (FREQ-JACK), R38.1
FREQ-POT: H1-H4.4 (FREQ-POT), U1.11 (PC3)
GND: C1.1, C2.1, C3.1, C4.2, C5.1, C6.1, C7.2, C8.C (NEG), C9.1, C10.C (NEG), C11.1, C12.1, C13.1, C14.C (NEG), C15.1, C16.1, C17.1, C18.1, C19.1, C20.1, C21.1, C22.1, C23.1, C24.C (NEG), C25.1, C26.1, C27.C (NEG), C33.1, C34.1, C35.1, C36.2, C43.1, C44.1, C45.C (NEG), C46.C (NEG), C47.1, C48.A (POS), C49.C (NEG), D1.1 (A1), H1-H4.3 (GND), H1-H4.9 (GND), H1-H4.13 (GND), H1-H4.19 (GND), H1-H4.32 (GND), H5.3 (GND), H5.5 (GND), H5.9 (GND), H7.3 (GND), H7.4 (GND), H7.5 (GND), H7.6 (GND), H7.7 (GND), H7.8 (GND), JP1.3, Q1.2 (E), R7.1, R21.1, R31.1, R46.1, U1.12 (VSSA), U1.18 (VSS4), U1.26 (PB0), U1.28 (PB2), U1.60 (BOOT0), U1.63 (VSS3), U2.6 (INH), U2.7 (VEE), U2.8 (VSS), U3.4 (DGND), U3.15 (PGND), U3.19 (AGND), U3.26 (CSB), U3.29 (DGND), U4.3 (IN+), U4.5 (+), U4.10 (+), U4.11 (NEG), U4.12 (+), U5.3 (IN+), U5.4 (NEG), U5.5 (+), U6.3 (IN+), U6.5 (+), U7.1 (GND), U8.1 (C)
I2C-SCL: R5.1, U1.29 (PB10), U3.28 (SCLK)
I2C-SDA: R6.1, U1.30 (PB11), U3.27 (SDIN)
I2S-LRCK: U1.33 (PB12), U3.9 (PBLRC), U3.11 (RECLRC)
I2S-SCK: U1.34 (PB13), U3.7 (BCLK)
I2S-SIN: U1.35 (PB14), U3.10 (RECDAT)
I2S-SOUT: U1.36 (PB15), U3.8 (PBDAT)
IN: C42.A (POS), U3.23 (RLINEIN)
IN-JACK: H1-H4.25 (IN-JACK), R45.1
IN-SW: H1-H4.21 (IN-SW), R27.2
JTCK/SWCLK: H5.4 (TCK/SWCLK), U1.49 (PA14)
JTDI: H5.8 (TDI), U1.50 (PA15)
JTDO/SWO: H5.6 (TDO/SWO), U1.55 (PB3)
JTMS/SWDIO: H5.2 (TMS/SWDIO), U1.46 (PA13)
LED-MODE-GRN: H1-H4.36 (LED-MODE-GRN), R44.2
LED-MODE-RED: H1-H4.38 (LED-MODE-RED), R43.2
LED-POLY-GRN: H1-H4.40 (LED-POLY-GRN), R42.2
LED-POLY-RED: H1-H4.39 (LED-POLY-RED), R41.2
MUTE: JP1.2, U3.25 (MUTE)
MUX-ADDR-0: U1.59 (PB7), U2.11 (A)
MUX-ADDR-1: U1.58 (PB6), U2.10 (B)
MUX-ADDR-2: U1.57 (PB5), U2.9 (C)
MUXED-POTS: U1.9 (PC1), U2.3 (COM)
unnamed: R43.1, U1.8 (PC0)
unnamed: C46.A (POS), R47.2, U7.3 (VIN)
unnamed: D3.A, L3.1
unnamed: D2.C, L2.1
unnamed: C29.1, R8.2, R12.2, R15.1, U4.6 (-)
unnamed: R44.1, U1.51 (PC10)
unnamed: C9.2, U1.31 (VSS1)
unnamed: C3.2, U1.47 (VSS2)
unnamed: R42.1, U1.52 (PC11)
unnamed: R41.1, U1.53 (PC12)
unnamed: C4.1, U1.5 (PD0), X1.2
unnamed: C7.1, U1.6 (PD1), X1.1
unnamed: C31.1, R10.2, R14.2, R17.1, U5.2 (IN-)
unnamed: C39.1, R34.1, R37.2, R40.2, U5.6 (-)
unnamed: C37.1, R32.1, R35.2, R38.2, U4.9 (-)
unnamed: C30.1, R9.2, R13.2, R16.1, U4.2 (IN-)
unnamed: C38.1, R33.1, R36.2, R39.2, U4.13 (-)
unnamed: C28.C (NEG), R20.1, R21.2
unnamed: C42.C (NEG), C43.2, R45.2, R46.2
unnamed: C41.C (NEG), R30.1, R31.2
unnamed: Q1.1 (B), R18.2
unnamed: C25.2, U3.1 (MCLK/XTI), X2.2
unnamed: C20.2, U3.2 (XTO), X2.1
unnamed: C32.1, R19.1, R20.2, R23.2, U6.6 (-)
unnamed: C32.2, R19.2, R22.1, U6.7 (OUT)
unnamed: C40.1, R25.2, R29.1, R30.2, U6.2 (IN-)
unnamed: C26.2, C27.A (POS), U3.20 (VMID)
unnamed: R7.2, U3.24 (LLINEIN)
unnamed: C40.2, R24.1, R29.2, U6.1 (OUT)
unnamed: H1-H4.6 (FREQ-SW), R4.1
unnamed: H7.1 (-12V), H7.2 (-12V), L2.2
unnamed: H7.9 (+12V), H7.10 (+12V), L3.2
NORM-PROBE: D1.3 (C1/A2), R26.1, R27.1, R28.1, U1.39 (PC8)
ODD-JACK: H1-H4.27 (ODD-JACK), R24.2
ODD-OUT: C41.A (POS), U3.16 (LOUT)
ODD-SW: H1-H4.29 (ODD-SW), R23.1
POS-ATT: H1-H4.22 (POS-ATT), U2.15 (X2)
POS-CV: C38.2, R33.2, U1.23 (PA7), U4.14 (OUT)
POS-JACK: H1-H4.30 (POS-JACK), R39.1
POS-POT: H1-H4.24 (POS-POT), U2.12 (X3)
RESET: C1.2, H5.10 (RESET), R1.1, U1.7 (NRST)
RX: H6.RX, R3.1
RX1: R3.2, U1.43 (PA10)
STRUCT-ATT: H1-H4.5 (STRUCT-ATT), U2.14 (X1)
STRUCT-CV: C30.2, R16.2, U1.22 (PA6), U4.1 (OUT)
STRUCT-JACK: H1-H4.7 (STRUCT-JACK), R9.1
STRUCT-POT: H1-H4.1 (STRUCT-POT), U1.10 (PC2)
STRUM: Q1.3 (C), R11.1, U1.16 (PA2)
STRUM-JACK: H1-H4.35 (STRUM-JACK), R18.1
STRUM-SW: H1-H4.37 (STRUM-SW), R26.2
SW-MODE: H1-H4.34 (SW-MODE), U1.61 (PB8)
SW-POLY: H1-H4.31 (SW-POLY), U1.62 (PB9)
TX: H6.TX, R2.1
TX1: R2.2, U1.42 (PA9)
V/OCT-CV: C39.2, R34.2, U1.15 (PA1), U5.7 (OUT)
V/OCT-JACK: H1-H4.23 (V/OCT-JACK), R40.1
V/OCT-SW: H1-H4.33 (V/OCT-SW), R28.2

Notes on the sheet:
Licensed: CC BY-SA 4.0 Board derived from work by Émilie Gillet of Mutable Instruments
tall-dog.com
TD-URSE-D-MB

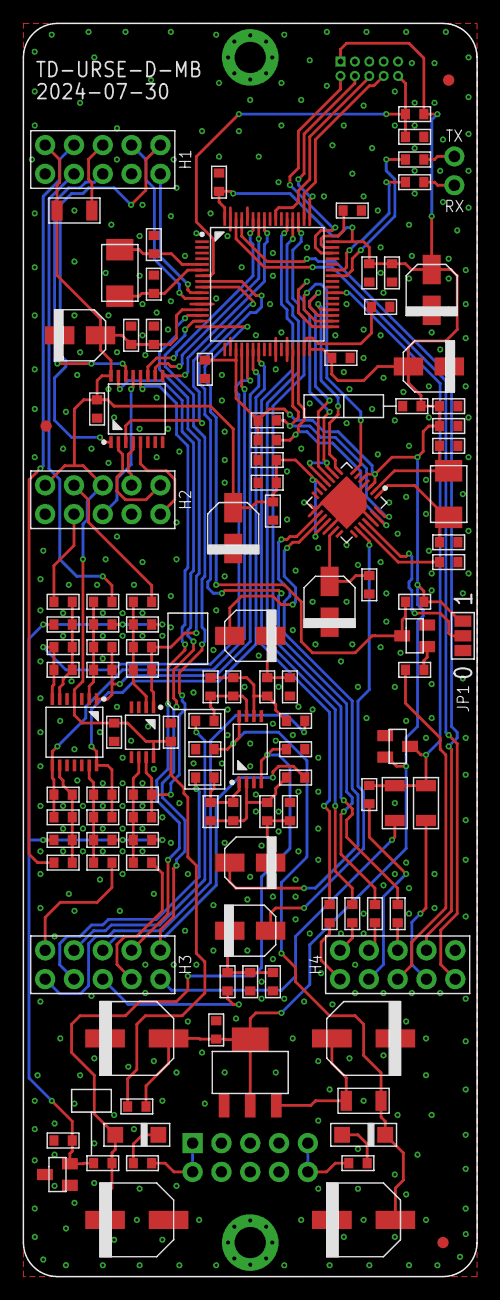
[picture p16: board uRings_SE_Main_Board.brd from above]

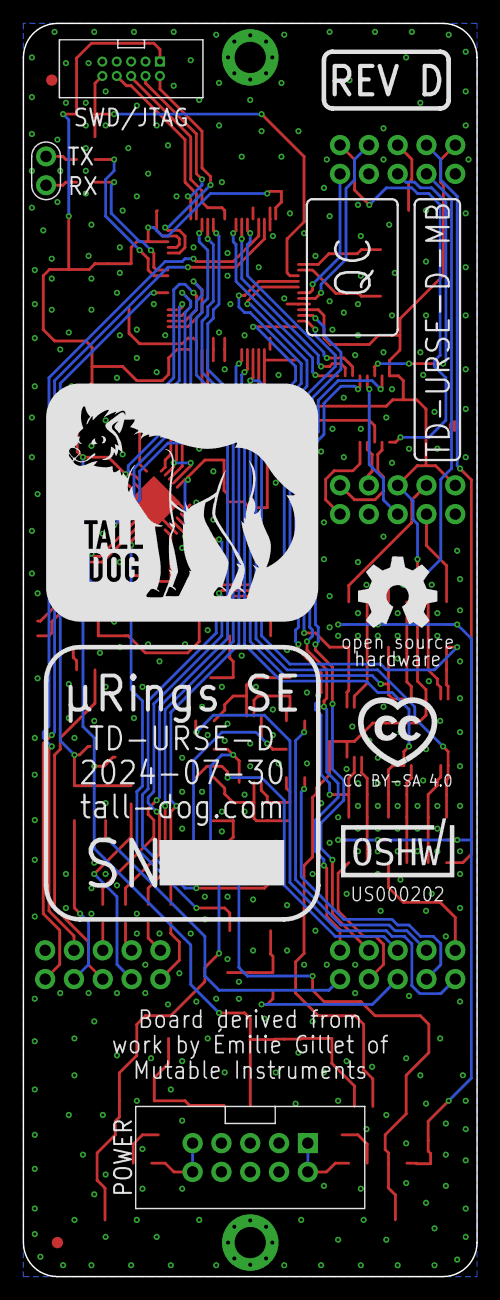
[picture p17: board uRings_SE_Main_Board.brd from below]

Board: 2 copper layers, 40.0 x 110.5 mm, 132 parts (11 on the bottom side), 100 nets.

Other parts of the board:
U$1: LOGO-PN
U$2, U$5, U$6: FIDUCIAL
U$3: LOGO-CC
U$4: LOGO-OSH
U$7: LOGO-SN
U$8: LOGO-OSHW
U$9: LOGO-TD
U$10: LOGO-REV
U$11: LOGO-QC

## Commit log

2018-11-17 initial commit, revision B production
    [uRings_SE_Assembly_Spacer.stl, uRings_SE_Assembly_Template.brd, uRings_SE_Control_Board.brd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]
2019-12-16 Updates for Revision C
    [uRings_SE_Control_Board.brd, uRings_SE_Control_Board.sch, uRings_SE_Control_Board_BOM.csv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]
2019-12-18 Cleanup and silkscreen artwork updates
    [uRings_SE_Control_Board.brd, uRings_SE_Control_Board.sch, uRings_SE_Main_Board.brd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]
2021-03-23 Revision C
    [uRings_SE_Assembly_Cap.stl, uRings_SE_Assembly_Spacer.stl, uRings_SE_Assembly_Template.brd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]
2024-07-24 updates in preparation for rev D production
    [uRings_SE_Assembly_Cap.step, uRings_SE_Assembly_Spacer.step, uRings_SE_Control_Board.brd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]
2024-08-08 revision D updates continued
    [uRings_SE_Assembly_Template.brd, uRings_SE_Control_Board.brd, uRings_SE_Control_Board.sch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]
